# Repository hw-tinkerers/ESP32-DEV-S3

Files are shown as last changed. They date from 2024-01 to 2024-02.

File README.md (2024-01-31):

# ESP32-S3_Dev_Board
This development board is based on ESP32-S3 chipset which is aimed to solve the problem having to carry multiple tools to debug and capture data on RS485 and CAN bus.

<strong> Front view (Rendering)</strong>
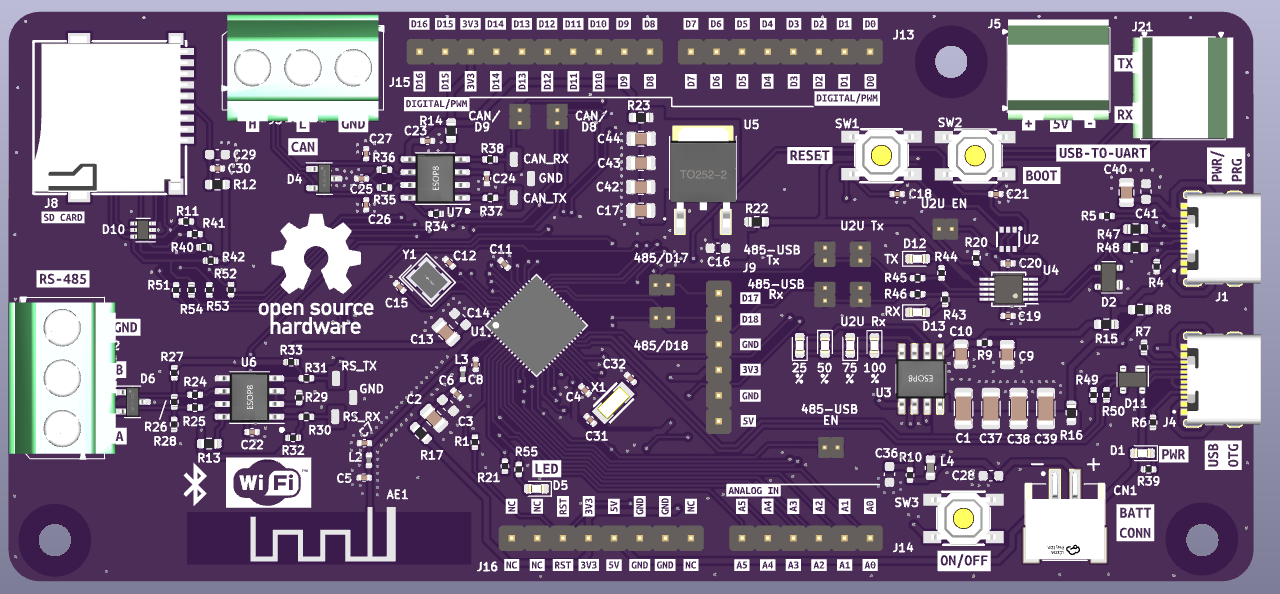
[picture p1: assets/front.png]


<strong> Back view (Rendering)</strong>
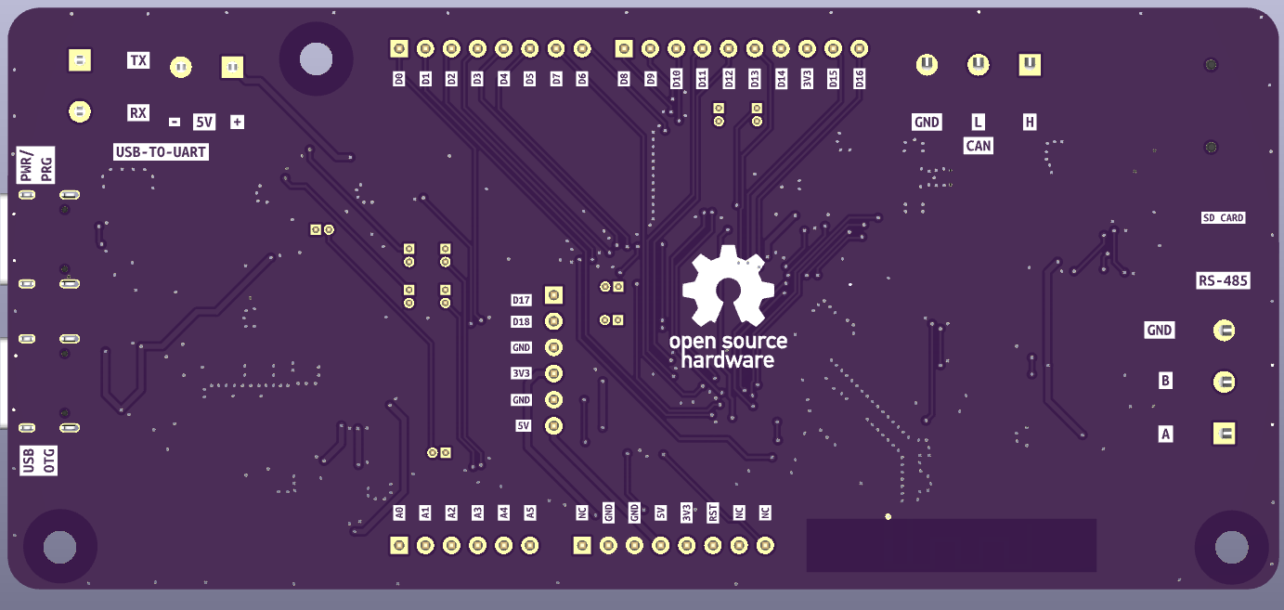
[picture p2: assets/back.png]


The board is capable of operating in multiple modes.
1. With Firmware support (Still in making):
    1. CAN bus Decoder
    2. RS485 Decoder 

2. Standalone Hardware support:
    1. RS485 to USB converter
    2. USB to UART converter

3. Normal Development baord for ESP32-S3 Development.

<strong>The Board supports a wide variety of features.</strong>

| Interface | Controller | Driver/Component |
| --- | --- | --- |
| UART | on-chip | serial port |
GPIO | on-chip | gpio |
PINMUX | on-chip | pinmux |
USB-JTAG | on-chip | hardware interface
SPI Master | on-chip | spi
TWAI/CAN controller | on-chip | can
ADC | on-chip | adc
Timers | on-chip | counter
Watchdog | on-chip | watchdog	
TRNG | on-chip | entropy
MCPWM | on-chip | pwm 
PCNT | on-chip | qdec
GDMA | on-chip | dma
LEDC | on-chip | pwm
CAN trasnceiver | on-board | can
RS485 transceiver | on-board | serial-port
UART-to-USB | on-board | Hardare based

<strong>Development enviroinment support </strong>
The board is designed keeping open-source support in mind.
The main motive is to provide support on multiple development environments to cater to different people ranging from begginers to professionls. 

The supported platforms are listed below

1. Arduino IDE
2. ESP-IDF
3. Zephyr-RTOS

The guide on getting started on each platform is still in making. Stay tuned for further updates.

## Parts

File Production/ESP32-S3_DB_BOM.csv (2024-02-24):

Designator | Footprint | Qty | Value | LCSC Part Number | MFR PN
C1, C37, C38, C39 | ESP32-S3_Dev_Board:C_1206_3216Metric | 4 | 22uF | C12891 | CL31A226KAHNNNE
C2, C9, C10, C13, C17, C40, C42, C43, C44 | ESP32-S3_Dev_Board:C_0805_2012Metric | 9 | 10uF | C15850 | CL21A106KAYNNNE
C3, C14, C16, C29, C41 | ESP32-S3_Dev_Board:C_0603_1608Metric | 5 | 1uF | C14664 | CC0603KRX5R8BB105
C4, C6, C8, C11, C18, C19, C20, C21, C22, C23, C24, C30 | ESP32-S3_Dev_Board:C_0402_1005Metric | 12 | 100nF | C2173920 | EMK107B7104KAHT
C5, C7 | ESP32-S3_Dev_Board:C_0402_1005Metric | 2 | 3.3pF | C327287 | CC0402BRNPO9BN3R3
C12, C15, C31, C32 | ESP32-S3_Dev_Board:C_0402_1005Metric | 4 | 15pF | C326789 | CC0402GRNPO8BN150
C25 | ESP32-S3_Dev_Board:C_0402_1005Metric | 1 | 10nF | C458948 | MT15B103K250CT
C28, C36 | ESP32-S3_Dev_Board:C_0603_1608Metric | 2 | 22uF | C2762594 | CL10A226MO7JZNC
CN1 | ESP32-S3_Dev_Board:JST_2mm | 1 | JST_Battery | C295747 | S2B-PH-SM4-TB(LF)(SN)
D1 | ESP32-S3_Dev_Board:LED_0603_1608Metric | 1 | BLUE | C84266 | NCD0603B1
D2, D11 | ESP32-S3_Dev_Board:SOT-143 | 2 | PRTR5V0U2X | C2827688 | PRTR5V0U2X
D3, D5, D7, D8, D9, D12, D13 | ESP32-S3_Dev_Board:LED_0603_1608Metric | 7 | GREEN | C84264 | NCD0603C1
D4 | ESP32-S3_Dev_Board:SOT-23-3 | 1 | PESD2CAN | C284078 | PESD2CAN
D6 | ESP32-S3_Dev_Board:SOT-23-3 | 1 | SM712_C293966 | C293966 | SM712
D10 | ESP32-S3_Dev_Board:SOT-363_SC-70-6 | 1 | PESD3V3L5UY,115 | C477992 | PESD3V3L5UY,115
J1, J4 | ESP32-S3_Dev_Board:tyye_c_connector | 2 | TYPE-C-31-M12_13 | C165948 | TYPE-C-31-M-12
J8 | ESP32-S3_Dev_Board:TF-SMD_TF-012 | 1 | Micro_SD_Card_Det1 | C5333937 | TF-012-P9
L2, L3 | ESP32-S3_Dev_Board:L_0402_1005Metric | 2 | 2.2nH | C76790 | MLK1005S2N2ST000
L4 | ESP32-S3_Dev_Board:L_0603_1608Metric | 1 | 1uH | C576540 | LQM18PN1R0MFHD
R1, R11, R21, R27, R28, R29, R40, R41, R42 | ESP32-S3_Dev_Board:R_0402_1005Metric | 9 | 10k | C60490 | RC0402FR-0710KL
R36, R35 | ESP32-S3_Dev_Board:R_0402_1005Metric | 2 | 59E | C273340 | RC0402FR-0759RL
R4, R5, R6, R7, R20, R32, R33, R34 | ESP32-S3_Dev_Board:R_0402_1005Metric | 8 | 5k1 | C105872 | RC0402FR-075K1L
R9 | ESP32-S3_Dev_Board:R_0402_1005Metric | 1 | 2E | C477639 | RC0402FR-072R1L
R10 | ESP32-S3_Dev_Board:R_0402_1005Metric | 1 | 0.5E | C346785 | CSR0402FKR500
R12, R13, R14, R15, R16, R17, R22, R23, R47, R48 | ESP32-S3_Dev_Board:R_0603_1608Metric | 10 | 0E | C95177 | RC0603JR-070RL
R24, R25, R30, R31, R37, R38, R45, R46, R49, R50, R51, R52, R53, R54 | ESP32-S3_Dev_Board:R_0402_1005Metric | 14 | 10E | C102753 | RTT02100JTH
R26 | ESP32-S3_Dev_Board:R_0402_1005Metric | 1 | 120E | C114758 | RC0402FR-07120RL
R39, R43, R44, R55 | ESP32-S3_Dev_Board:R_0402_1005Metric | 4 | 500 | C137970 | RC0402FR-07499RL
SW1 | ESP32-S3_Dev_Board:KEY-SMD_4P-L5.2-W5.2-P3.70-LS6.4 | 1 | RESET | C92584 | K2-1187SQ-A4SW-06
SW2 | ESP32-S3_Dev_Board:KEY-SMD_4P-L5.2-W5.2-P3.70-LS6.4 | 1 | BOOT | C92584 | K2-1187SQ-A4SW-06
SW3 | ESP32-S3_Dev_Board:KEY-SMD_4P-L5.2-W5.2-P3.70-LS6.4 | 1 | ON/OFF | C92584 | K2-1187SQ-A4SW-06
U1 | ESP32-S3_Dev_Board:QFN-56_L7.0-W7.0-P0.40-TL-EP4.0 | 1 | ESP32-S3FH4R2 | C3013940 | ESP32-S3FH4R2
U2 | ESP32-S3_Dev_Board:SC-70-6_L2.2-W1.3-P0.65-LS2.1-BR | 1 | UMH3N | C62892 | UMH3N
U3 | ESP32-S3_Dev_Board:ESOP-8 | 1 | IP5306 | C181692 | IP5306
U4 | ESP32-S3_Dev_Board:MSOP-10_3x3mm_P0.5mm | 1 | CH340X | C3035748 | CH340X
U5 | ESP32-S3_Dev_Board:DPAK | 1 | LD1117DT33CTR | C36395 | LD1117DT33CTR
U6 | ESP32-S3_Dev_Board:SOP-8_3.9x4.9mm_P1.27mm | 1 | SP3071EEN-L/TR | C28746 | SP3071EEN-L/TR
U7 | ESP32-S3_Dev_Board:SOP-8_3.9x4.9mm_P1.27mm | 1 | ATA6561-GAQW-N | C616016 | ATA6561-GAQW-N
X1 | ESP32-S3_Dev_Board:CRYSTAL-SMD_L3.2-W1.5 | 1 | 32.768KHz | C7206317 | RN32768016
Y1 | ESP32-S3_Dev_Board:CRYSTAL-SMD_4P-L3.2-W2.5-BL | 1 | 40MHz | C2901712 | SX3B40.000F1210F30

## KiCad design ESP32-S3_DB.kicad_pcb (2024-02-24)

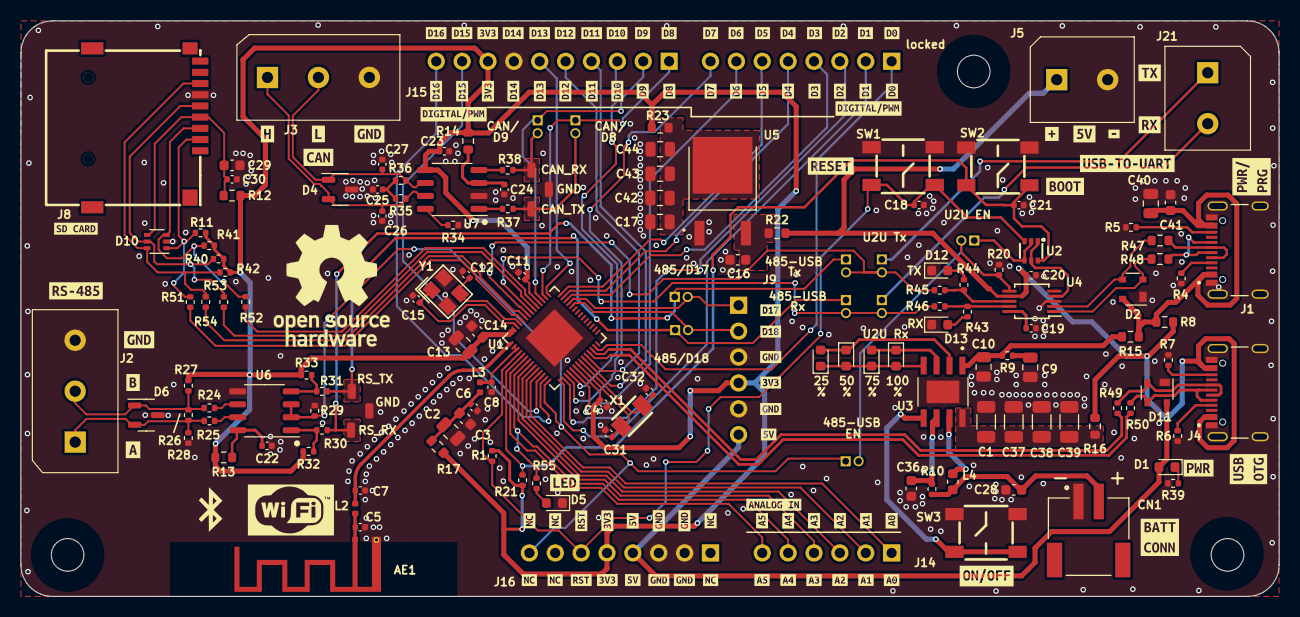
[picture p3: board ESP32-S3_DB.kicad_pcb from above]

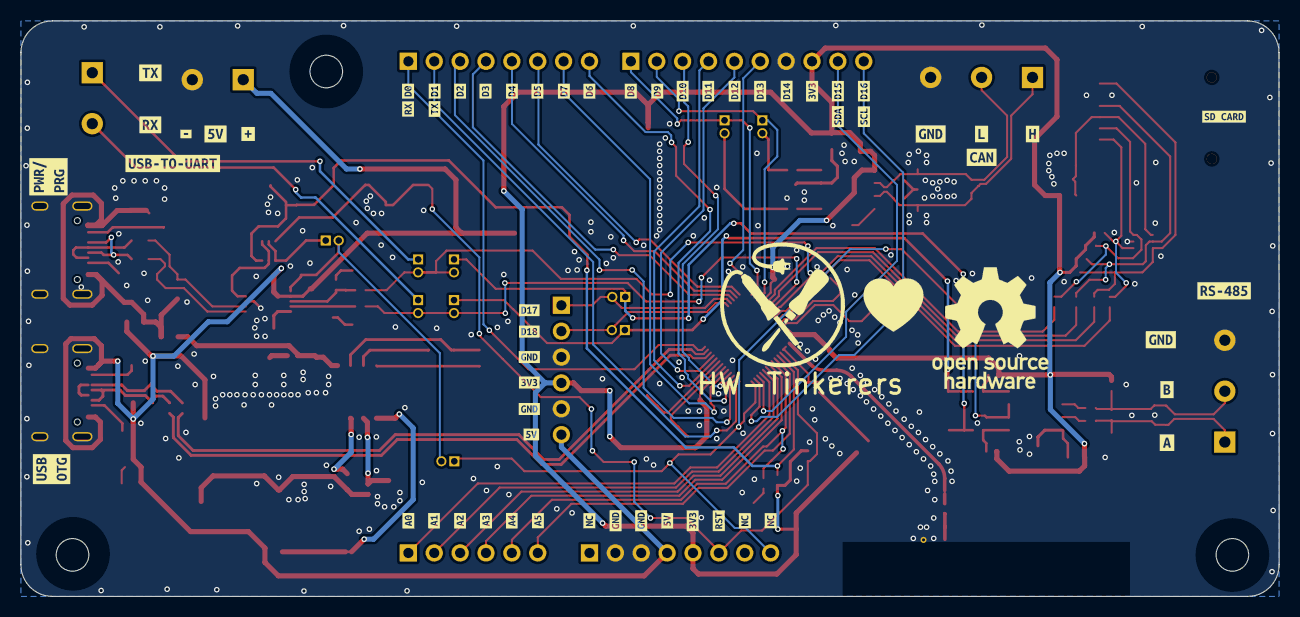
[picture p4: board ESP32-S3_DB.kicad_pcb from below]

Board: 4 copper layers, 123.5 x 56.5 mm, 310 parts (60 on the bottom side), 104 nets.

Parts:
AE1: Antenna_Shield; BLE_ANTENNA
C1, C37, C38, C39: 22uF; C_1206_3216Metric
C2, C9, C10, C13, C17, C40, C42, C43, C44: 10uF; C_0805_2012Metric
C3, C14, C16, C29, C41: 1uF; C_0603_1608Metric
C4, C6, C8, C11, C18, C19, C20, C21, C22, C23, C24, C30: 100nF; C_0402_1005Metric
C5, C7: 3.3pF; C_0402_1005Metric
C12, C15, C31, C32: 15pF; C_0402_1005Metric
C25, C26, C27: 10nF; C_0402_1005Metric
C28, C36: 22uF; C_0603_1608Metric
CN1: JST_Battery; JST_2mm
D1: BLUE; LED_0603_1608Metric
D2, D11: PRTR5V0U2X; SOT-143
D3, D5, D7, D8, D9, D12, D13: GREEN; LED_0603_1608Metric
D4: PESD2CAN; SOT-23-3
D6: SM712_C293966; SOT-23-3
D10: PESD3V3L5UY,115; SOT-363_SC-70-6
H1, H2, H3: MountingHole; MountingHole_3.2mm_M3
J1, J4: TYPE-C-31-M12_13; tyye_c_connector
J2: A - B; 3P_Screw_Terminal
J3: H - L; 3P_Screw_Terminal
J5: EXT_LOAD; 2P_Screw_Terminal
J6: R4_TX; PinHeader_1x02_P1.27mm_Vertical
J7: R4_RX; PinHeader_1x02_P1.27mm_Vertical
J8: Micro_SD_Card_Det1; TF-SMD_TF-012
J9, J14: Conn_01x06; PinHeader_1x06_P2.54mm_Vertical
J10: U2RS485_TX; PinHeader_1x02_P1.27mm_Vertical
J11: CAN_TX; PinHeader_1x02_P1.27mm_Vertical
J12: CAN_RX; PinHeader_1x02_P1.27mm_Vertical
J15: Conn_01x10; PinHeader_1x10_P2.54mm_Vertical
J16: Conn_01x08; PinHeader_1x08_P2.54mm_Vertical
J17: U2RS485_RX; PinHeader_1x02_P1.27mm_Vertical
J18: U2RS485_DE_~{RE}; PinHeader_1x02_P1.27mm_Vertical
J19: U2U_TX; PinHeader_1x02_P1.27mm_Vertical
J20: U2U_RX; PinHeader_1x02_P1.27mm_Vertical
J21: U2U; 2P_Screw_Terminal
J22: PROG_Default; PinHeader_1x02_P1.27mm_Vertical
L2, L3: 2.2nH; L_0402_1005Metric
L4: 1uH; L_0603_1608Metric
R1, R11, R21, R27, R28, R29, R40, R41, R42: 10k; R_0402_1005Metric
R4, R5, R6, R7, R20, R32, R33, R34: 5k1; R_0402_1005Metric
R8, R12, R13, R14, R15, R16, R17, R22, R23, R47, R48: 0E; R_0603_1608Metric
R9: 2E; R_0402_1005Metric
R10: 0.5E; R_0402_1005Metric
R24, R25, R30, R31, R37, R38, R45, R46, R49, R50, R51, R52, R53, R54: 10E; R_0402_1005Metric
R26: 120E; R_0402_1005Metric
R35: 59E; R_0402_1005Metric
R36: 59; R_0402_1005Metric
R39, R43, R44, R55: 500; R_0402_1005Metric
SW1: RESET; KEY-SMD_4P-L5.2-W5.2-P3.70-LS6.4
SW2: BOOT; KEY-SMD_4P-L5.2-W5.2-P3.70-LS6.4
SW3: ON/OFF; KEY-SMD_4P-L5.2-W5.2-P3.70-LS6.4
SYM1, SYM2: Logo_Open_Hardware_Large; OSHW-Logo_11.4x12mm_SilkScreen
TP1: RS_RX; Test_Pad_1.5mm
TP2: RS_TX; Test_Pad_1.5mm
TP3: CAN_TX; Test_Pad_1.5mm
TP4: CAN_RX; Test_Pad_1.5mm
TP5, TP6: GND; Test_Pad_1.5mm
U1: ESP32-S3FH4R2; QFN-56_L7.0-W7.0-P0.40-TL-EP4.0
U2: UMH3N; SC-70-6_L2.2-W1.3-P0.65-LS2.1-BR
U3: IP5306; ESOP-8
U4: CH340X; MSOP-10_3x3mm_P0.5mm
U5: LD1117DT33CTR; DPAK
U6: SP3071EEN-L/TR; SOP-8_3.9x4.9mm_P1.27mm
U7: ATA6561-GAQW-N; SOP-8_3.9x4.9mm_P1.27mm
X1: 32.768KHz; CRYSTAL-SMD_L3.2-W1.5
Y1: 40MHz; CRYSTAL-SMD_4P-L3.2-W2.5-BL
kibuzzard-65A92C15, kibuzzard-65A92C15#2, kibuzzard-65A92C15#3: G***; kibuzzard-65A92C15
kibuzzard-65A92C32, kibuzzard-65A92C32#2, kibuzzard-65A92C32#3: G***; kibuzzard-65A92C32
kibuzzard-65A92C44, kibuzzard-65A92C44#2, kibuzzard-65A92C44#3: G***; kibuzzard-65A92C44
kibuzzard-65A92C55, kibuzzard-65A92C55#2, kibuzzard-65A92C55#3: G***; kibuzzard-65A92C55
kibuzzard-65A92C85, kibuzzard-65A92C85#2, kibuzzard-65A92C85#3: G***; kibuzzard-65A92C85
kibuzzard-65A92C90, kibuzzard-65A92C90#2, kibuzzard-65A92C90#3: G***; kibuzzard-65A92C90
kibuzzard-65A92C99, kibuzzard-65A92C99#2, kibuzzard-65A92C99#3: G***; kibuzzard-65A92C99
kibuzzard-65A92CA3, kibuzzard-65A92CA3#2, kibuzzard-65A92CA3#3: G***; kibuzzard-65A92CA3
kibuzzard-65A92CE7, kibuzzard-65A92CE7#2: G***; kibuzzard-65A92CE7
kibuzzard-65A92E71, kibuzzard-65A92E71#2: G***; kibuzzard-65A92E71
kibuzzard-65A922D3, kibuzzard-65A922D3#2, kibuzzard-65A922D3#3: G***; kibuzzard-65A922D3
kibuzzard-65A922DA, kibuzzard-65A922DA#2, kibuzzard-65A922DA#3: G***; kibuzzard-65A922DA
kibuzzard-65A922E0, kibuzzard-65A922E0#2, kibuzzard-65A922E0#3: G***; kibuzzard-65A922E0
kibuzzard-65A922F7, kibuzzard-65A922F7#2, kibuzzard-65A922F7#3: G***; kibuzzard-65A922F7
kibuzzard-65A932A3, kibuzzard-65A932A3#2: G***; kibuzzard-65A932A3
kibuzzard-65A932F7, kibuzzard-65A932F7#2: G***; kibuzzard-65A932F7
kibuzzard-65A934AB, kibuzzard-65A934AB#2: G***; kibuzzard-65A934AB
kibuzzard-65A937AF, kibuzzard-65A937AF#2: G***; kibuzzard-65A937AF
kibuzzard-65A937DF: G***; kibuzzard-65A937DF
kibuzzard-65A9230D, kibuzzard-65A9230D#2, kibuzzard-65A9230D#3: G***; kibuzzard-65A9230D
kibuzzard-65A9357B: G***; kibuzzard-65A9357B
kibuzzard-65A9398B, kibuzzard-65A9398B#2: G***; kibuzzard-65A9398B
kibuzzard-65A92320, kibuzzard-65A92320#2, kibuzzard-65A92320#3: G***; kibuzzard-65A92320
kibuzzard-65A92621: G***; kibuzzard-65A92621
kibuzzard-65A93244, kibuzzard-65A93244#2: G***; kibuzzard-65A93244
kibuzzard-65A93266, kibuzzard-65A93266#2: G***; kibuzzard-65A93266
kibuzzard-65A93272, kibuzzard-65A93272#2: G***; kibuzzard-65A93272
kibuzzard-65A93313, kibuzzard-65A93313#2: G***; kibuzzard-65A93313
kibuzzard-65A93322, kibuzzard-65A93322#2: G***; kibuzzard-65A93322
kibuzzard-65A93334, kibuzzard-65A93334#2: G***; kibuzzard-65A93334
kibuzzard-65A93499, kibuzzard-65A93499#2: G***; kibuzzard-65A93499
kibuzzard-65A93960, kibuzzard-65A93960#2: G***; kibuzzard-65A93960
kibuzzard-65AB7A1C: G***; kibuzzard-65AB7A1C
kibuzzard-65AB7A3B, kibuzzard-65AB7A3B#2: G***; kibuzzard-65AB7A3B
kibuzzard-65AB7A4E, kibuzzard-65AB7A4E#2: G***; kibuzzard-65AB7A4E
kibuzzard-65AB7A5E, kibuzzard-65AB7A5E#2: G***; kibuzzard-65AB7A5E
kibuzzard-65AB7A9A, kibuzzard-65AB7A9A#2: G***; kibuzzard-65AB7A9A
kibuzzard-65AB7A9F: G***; kibuzzard-65AB7A9F
kibuzzard-65AB7A26, kibuzzard-65AB7A26#2: G***; kibuzzard-65AB7A26
kibuzzard-65AB7A41: G***; kibuzzard-65AB7A41
kibuzzard-65AB7A48: G***; kibuzzard-65AB7A48
kibuzzard-65AB7A58: G***; kibuzzard-65AB7A58
kibuzzard-65AB7A95: G***; kibuzzard-65AB7A95
kibuzzard-65AB7AA6, kibuzzard-65AB7AA6#2: G***; kibuzzard-65AB7AA6
kibuzzard-65AB7AAC: G***; kibuzzard-65AB7AAC
kibuzzard-65AB7AB4, kibuzzard-65AB7AB4#2: G***; kibuzzard-65AB7AB4
kibuzzard-65AB7ABA: G***; kibuzzard-65AB7ABA
kibuzzard-65AB7AC0, kibuzzard-65AB7AC0#2: G***; kibuzzard-65AB7AC0
kibuzzard-65AB7B50: G***; kibuzzard-65AB7B50
kibuzzard-65AB7B59, kibuzzard-65AB7B59#2: G***; kibuzzard-65AB7B59
kibuzzard-65AB7B60: G***; kibuzzard-65AB7B60
kibuzzard-65AB7B68, kibuzzard-65AB7B68#2: G***; kibuzzard-65AB7B68
kibuzzard-65AB72BB, kibuzzard-65AB72BB#2, kibuzzard-65AB72BB#3: G***; kibuzzard-65AB72BB
kibuzzard-65AB72CF, kibuzzard-65AB72CF#2, kibuzzard-65AB72CF#3: G***; kibuzzard-65AB72CF
kibuzzard-65AB99D3, kibuzzard-65AB99D3#2: G***; kibuzzard-65AB99D3
kibuzzard-65AB729F, kibuzzard-65AB729F#2, kibuzzard-65AB729F#3, kibuzzard-65AB729F#4, kibuzzard-65AB729F#5, kibuzzard-65AB729F#6: G***; kibuzzard-65AB729F
kibuzzard-65AB730A, kibuzzard-65AB730A#2, kibuzzard-65AB730A#3: G***; kibuzzard-65AB730A
kibuzzard-65AB731E, kibuzzard-65AB731E#2, kibuzzard-65AB731E#3, kibuzzard-65AB731E#4, kibuzzard-65AB731E#5, kibuzzard-65AB731E#6: G***; kibuzzard-65AB731E
kibuzzard-65AB7281, kibuzzard-65AB7281#2, kibuzzard-65AB7281#3: G***; kibuzzard-65AB7281
kibuzzard-65ABCD1E, kibuzzard-65ABCD1E#2: G***; kibuzzard-65ABCD1E
kibuzzard-65ABCD6A, kibuzzard-65ABCD6A#2: G***; kibuzzard-65ABCD6A
kibuzzard-65ABCD30, kibuzzard-65ABCD30#2: G***; kibuzzard-65ABCD30
kibuzzard-65ABCD42, kibuzzard-65ABCD42#2, kibuzzard-65ABCD42#3, kibuzzard-65ABCD42#4: G***; kibuzzard-65ABCD42
kibuzzard-65ABCD53, kibuzzard-65ABCD53#2: G***; kibuzzard-65ABCD53
kibuzzard-65ABCFED: G***; kibuzzard-65ABCFED
kibuzzard-65ABD001: G***; kibuzzard-65ABD001
kibuzzard-65ABD06D, kibuzzard-65ABD06D#2: G***; kibuzzard-65ABD06D
kibuzzard-65ABD087, kibuzzard-65ABD087#2: G***; kibuzzard-65ABD087
kibuzzard-65AD136A: G***; kibuzzard-65AD136A
kibuzzard-65AD1381: G***; kibuzzard-65AD1381
kibuzzard-65CC7CB6: G***; kibuzzard-65CC7CB6
kibuzzard-65CC7CF4: G***; kibuzzard-65CC7CF4
kibuzzard-65CDB80D: G***; kibuzzard-65CDB80D
kibuzzard-65CDB868: G***; kibuzzard-65CDB868
locked: Conn_01x08; PinHeader_1x08_P2.54mm_Vertical

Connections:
/3V3: C4.1, C11.1, C13.1, C14.1, C23.1, J9.4, J15.8, J16.5, R1.1, R11.2, R12.1, R13.2, R14.1, R17.1, R21.1, R23.2, R27.2, R32.2, R33.2, R40.2, R41.2, R42.2, U1.20 (VDD3P3_RTC), U1.46 (VDD3P3_CPU), U1.55 (VDDA), U1.56 (VDDA), U7.5 (VIO)
/5V: C20.2, D1.2 (A), D11.4 (VCC), J4.A4 (VBUS), J4.B4 (VBUS), J5.1, J9.6, J16.4, R8.2, R16.2, R22.1, U4.7 (VCC)
/485_TRANS_RX: J7.1, J17.1, R30.1, TP1.1
/485_TRANS_TX: J6.1, J10.1, R31.1, TP2.1
/BOOT: C21.2, R21.2, SW2.2, U1.5 (GPIO0), U2.6
/CAN TRANSCEIVER/RXD: R38.1, U7.4 (RXD)
/CAN TRANSCEIVER/TXD: R37.1, U7.1 (TXD)
/CAN_N: C27.2, D4.1, J3.2, R36.1, U7.6 (CANL)
/CAN_P: C26.1, D4.2, J3.1, R35.2, U7.7 (CANH)
/CAN_RXD/MTDO: J12.1, J15.2, U1.45 (MTDO)
/CAN_TRANS_RXD: J12.2, R38.2, TP4.1
/CAN_TRANS_TXD: J11.2, R37.2, TP3.1
/CAN_TXD/MTCK: J11.1, J15.1, U1.44 (MTCK)
/D+: D2.2 (I/O_1), R48.2, U4.1 (UD+)
/D-: D2.3 (I/O_2), R47.2, U4.2 (UD-)
/ESP32-S3/D+: R49.2, U1.26 (GPIO20)
/ESP32-S3/D-: R50.2, U1.25 (GPIO19)
/ESP32-S3/XTALN: C32.1, U1.22 (XTAL_32K_N), X1.2
/ESP32-S3/XTALP: C31.1, U1.21 (XTAL_32K_P), X1.1
/EXTERNAL CONNECTORS/CC1: J4.A5 (CC1), R6.1
/EXTERNAL CONNECTORS/CC2: J4.B5 (CC2), R7.1
/GPIO1: J14.6, U1.6 (GPIO1)
/GPIO2: J14.5, R55.2, U1.7 (GPIO2)
/GPIO3: J14.4, U1.8 (GPIO3)
/GPIO4: J14.3, U1.9 (GPIO4)
/GPIO5: J14.2, U1.10 (GPIO5)
/GPIO6: J14.1, U1.11 (GPIO6)
/GPIO7: J15.9, U1.12 (GPIO7)
/GPIO8: J15.10, U1.13 (GPIO8)
/GPIO10: U1.15 (GPIO10), locked.2
/GPIO11: U1.16 (GPIO11), locked.3
/GPIO12: U1.17 (GPIO12), locked.8
/GPIO13: J15.3, U1.18 (GPIO13)
/GPIO14: U1.19 (GPIO14), locked.7
/GPIO17: J15.4, U1.23 (GPIO17)
/GPIO18: J15.5, U1.24 (GPIO18)
/GPIO21: U1.27 (GPIO21), locked.1
/GPIO35: U1.40 (GPIO35), locked.4
/GPIO36: U1.41 (GPIO36), locked.5
/GPIO37: U1.42 (GPIO37), locked.6
/GPIO40: J15.6, U1.43 (GPIO38)
/INPUT POWER/CC1: J1.A5 (CC1), R4.1
/INPUT POWER/CC2: J1.B5 (CC2), R5.1
/INPUT POWER/LED1: D3.2 (A), D7.1 (K), U3.2 (LED1)
/INPUT POWER/LED2: D8.2 (A), D9.1 (K), U3.3 (LED2)
/INPUT POWER/LED3: D3.1 (K), D7.2 (A), D8.1 (K), D9.2 (A), U3.4 (LED3)
/INPUT POWER/VIN: C40.1, C41.1, D2.4 (VCC), J1.A4 (VBUS), J1.B4 (VBUS), R8.1, R15.1
/MCU_SL_CLK: D10.5 (L4), J8.5 (CLK), R40.1, R53.1
/MCU_SL_MISO: D10.6 (L5), J8.7 (DAT0), R42.1, R54.2
/MCU_SL_MOSI: D10.3 (L2), J8.3 (CMD), R41.1, R52.2
/OTG_D+: D11.2 (I/O_1), J4.A6 (D+), J4.B6 (D+), R49.1
/OTG_D-: D11.3 (I/O_2), J4.A7 (D-), J4.B7 (D-), R50.1
/R4_~RE_DE: J16.8, J18.1, R29.2, U1.14 (GPIO9), U6.2 (~RE), U6.3 (DE)
/RESET: C18.2, J16.6, R1.2, SW1.2, U1.4 (CHIP_PU), U2.3
/RS485_N: D6.2, J2.1, R25.2, R26.1, R28.2
/RS485_P: D6.1, J2.2, R24.2, R26.2, R27.1
/RS-485_RX/GPIO34: J7.2, J9.1, U1.39 (GPIO34)
/RS-485_TX/GPIO33: J6.2, J9.2, U1.38 (GPIO33)
/RS_485/RS-485_DI: R31.2, R33.1, U6.4 (DI)
/RS_485/RS-485_RO: R30.2, R32.1, U6.1 (RO)
/RS_485/RS_485_N: R25.1, U6.7 (B)
/RS_485/RS_485_P: R24.1, U6.6 (A)
/SD_CARD/VDD: C29.1, C30.1, D10.4 (L3), J8.4 (VDD), R12.2
/TNOW: J18.2, J22.2, R20.2, U4.6 (TNOW)
/U2U_CONN_RX: J20.1, J21.2
/U2U_CONN_TX: J19.1, J21.1
/U2U_RXD: J10.2, J20.2, R46.2, U1.49 (U0TXD)
/U2U_TXD: J17.2, J19.2, R45.2, U1.50 (U0RXD)
/USB-TO-UART/485_TX: R44.2, R45.1, U4.8 (TXD)
/USB-TO-UART/DTR: J22.1, U2.2, U2.4
/USB-TO-UART/RTS: U2.1, U2.5, U4.4 (~RTS)
/USB-TO-UART/V3: C19.2, U4.10 (V3)
/V_BAT: C28.1, CN1.2, L4.2, R10.2
/~MCU_SL_CS: D10.1 (L1), J8.2 (DAT3/CD), R11.1, R51.1
GND: AE1.2 (Shield), C1.2, C2.2, C3.2, C4.2, C5.2, C6.2, C7.2, C8.2, C9.2, C10.2, C11.2, C12.2, C13.2, C14.2, C15.2, C16.2, C17.2, C18.1, C19.1, C20.1, C21.1, C22.2, C23.2, C24.1, C25.1, C26.2, C27.1, C28.2, C29.2, C30.2, C31.2, C32.2, C36.2, C37.2, C38.2, C39.2, C40.2, C41.2, C42.2, C43.2, C44.2, CN1.1, D2.1 (GND), D4.3, D5.1 (K), D6.3, D10.2 (VN), D11.1 (GND), D12.1 (K), D13.1 (K), J1.A1 (GND), J1.B1 (GND), J1.S (SHIELD), J2.3, J3.3, J4.A1 (GND), J4.B1 (GND), J4.S (SHIELD), J5.2, J8.6 (VSS), J9.3, J9.5, J15.7, J16.2, J16.3, R4.2, R5.2, R6.2, R7.2, R20.1, R28.1, R29.1, R34.2, R39.2, SW1.1, SW2.1, SW3.2, TP5.1, TP6.1, U1.57 (GND), U3.9 (EP), U4.3 (GND), U5.1 (GND), U6.5 (GND), U7.2 (GND), Y1.2, Y1.4
unnamed: AE1.1 (A), C5.1, L2.1
unnamed: C2.1, C3.1, C6.1, L3.1, R17.2
unnamed: C8.1, L3.2, U1.2 (VDD3P3), U1.3 (VDD3P3)
unnamed: C9.1, R9.2
unnamed: C25.2, R35.1, R36.2
unnamed: D1.1 (K), R39.1
unnamed: D5.2 (A), R55.1
unnamed: D12.2 (A), R44.1
unnamed: D13.2 (A), R43.1
unnamed: J1.A6 (D+), J1.B6 (D+), R48.1
unnamed: J1.A7 (D-), J1.B7 (D-), R47.1
unnamed: R54.1, U1.51 (GPIO45)
unnamed: R51.2, U1.52 (GPIO46)
unnamed: C7.1, L2.2, U1.1 (LNA_IN)
unnamed: R52.1, U1.47 (MTDI)
unnamed: R53.2, U1.48 (MTMS)
unnamed: C12.1, U1.53 (XTAL_N), Y1.3
unnamed: C15.1, U1.54 (XTAL_P), Y1.1
unnamed: C36.1, R10.1, U3.6 (BAT)
unnamed: SW3.1, U3.5 (KEY)
unnamed: L4.1, U3.7 (SW)
unnamed: C10.1, R9.1, R15.2, U3.1 (VIN)
unnamed: C1.1, C37.1, C38.1, C39.1, R16.1, U3.8 (VOUT)
unnamed: R43.2, R46.1, U4.9 (RXD)
unnamed: C16.1, R22.2, U5.3 (VIN)
unnamed: C17.1, C42.1, C43.1, C44.1, R23.1, U5.2 (VOUT)
unnamed: C22.1, R13.1, U6.8 (VCC)
unnamed: R34.1, U7.8 (STBY)
unnamed: C24.2, R14.2, U7.3 (VCC)

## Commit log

2023-08-22 Schematic file with Symbol library
    [ESP32-S3_DB.kicad_pcb, ESP32-S3_DB.kicad_sch]
2023-08-22 Started designed the schematics
    Placed passives for supply pins and antenna
    [ESP32-S3_DB.kicad_sch]
2023-08-23 Added External Flash and Power sheets
    Added External Flash and Power sheets. Finished adding all the passives at their respective pins. Incorrect Pin number and signal corrected.
    [ESP32-S3_DB.kicad_sch, EXT_FLASH.kicad_sch, POWER.kicad_sch]
2023-09-04 Created Block arrangement and added USB C connector
    [3V3_Power.kicad_sch, ESP32-S3-MCU.kicad_sch, ESP32-S3_DB.kicad_sch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]
2023-09-04 completed USB-C wiring and added flash
    [ESP32-S3_DB.kicad_sch, EXT_FLASH.kicad_sch, INPUT POWER.kicad_sch]
2023-09-06 Added USB-To-UART Converter
    [ESP32-S3-MCU.kicad_sch, ESP32-S3_DB.kicad_sch, EXT_FLASH.kicad_sch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]
2023-09-12 Made USB-To-UART connections
    [ESP32-S3-MCU.kicad_sch, ESP32-S3_DB.kicad_sch, USB-To-UART.kicad_sch]
2023-09-16 Added RS-485 Transceiver
    [3V3_Power.kicad_sch, ESP32-S3-MCU.kicad_sch, ESP32-S3_DB.kicad_sch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]
2023-09-17 Minor UART corrections
2023-09-17 UART Tx and Rx correctly placed
    [ESP32-S3_DB.kicad_sch, USB-To-UART.kicad_sch]
2023-09-17 Completed RS-485 connections
    [CAN-TRANSCEIVER.kicad_sch, ESP32-S3-MCU.kicad_sch, ESP32-S3_DB.kicad_sch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]
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2023-09-18 Added IP5306 for power path management
    [CAN-TRANSCEIVER.kicad_sch, ESP32-S3-MCU.kicad_sch, ESP32-S3_DB.kicad_sch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]
2023-09-19 Assigned UART port 2 for RS-485
    [ESP32-S3-MCU.kicad_sch, ESP32-S3_DB.kicad_sch, External_connec.kicad_sch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]
2023-09-21 Added SD card interface
    [ESP32-S3-MCU.kicad_sch, ESP32-S3_DB.kicad_sch, SD_Card.kicad_sch]
2023-09-23 Added SD card protection
    [ESP32-S3_DB.kicad_sch, SD_Card.kicad_sch]
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2023-09-24 Added 32.768KHz crystal for lower power usage
    [ESP32-S3-MCU.kicad_sch]
2023-09-27 Assigned PN and Footprint for C
    [3V3_Power.kicad_sch, CAN-TRANSCEIVER.kicad_sch, ESP32-S3-MCU.kicad_sch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]
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2023-10-16 Arranged power section on PCB
    [ESP32-S3_DB.kicad_pcb, ESP32-S3_DB.kicad_sch, INPUT POWER.kicad_sch]
2023-10-18 Added bulk Decoupling and arranged components
    [3V3_Power.kicad_sch, ESP32-S3-MCU.kicad_sch, ESP32-S3_DB.kicad_pcb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]
2023-10-20 Changed USB C footprint and arranged components
    [ESP32-S3_DB.kicad_pcb, External_connec.kicad_sch, INPUT POWER.kicad_sch]
2023-10-22 Placed RS-485, CAN Transceiver and battery charger
    [CAN-TRANSCEIVER.kicad_sch, ESP32-S3-MCU.kicad_sch, ESP32-S3_DB.kicad_pcb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]
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2023-10-24 Placed all the components and added OSHW symbol
    [ESP32-S3-MCU.kicad_sch, ESP32-S3_DB.kicad_pcb, ESP32-S3_DB.kicad_sch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]
2023-10-25 Corrected schematic to PCB export error and warings and IP5306 and SD card section
    [3V3_Power.kicad_sch, ESP32-S3-MCU.kicad_sch, ESP32-S3_DB.kicad_pcb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]
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2023-10-27 Corrected RS485 schematic
    [3V3_Power.kicad_sch, CAN-TRANSCEIVER.kicad_sch, ESP32-S3_DB.kicad_sch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]
2023-10-27 Made minor changes in connectors sheet
    [ESP32-S3_DB.kicad_sch, External_connec.kicad_sch]
2023-10-27 Added CAN Jumpers, changed jumper pitch to 1.27mm
    [CAN-TRANSCEIVER.kicad_sch, ESP32-S3-MCU.kicad_sch, ESP32-S3_DB.kicad_pcb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]
2023-10-28 Changed GPIO headers to Arduino style
    [ESP32-S3_DB.kicad_pcb, ESP32-S3_DB.kicad_sch, External_connec.kicad_sch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]
2023-10-30 Arranged IP5306, Added support for USB-To-RS485
    [ESP32-S3_DB.kicad_pcb, ESP32-S3_DB.kicad_sch, External_connec.kicad_sch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]
2023-10-30 Arranged arduino headers as per the Uno R3 dimensions
    [ESP32-S3_DB.kicad_pcb]
2023-10-31 Minor changes in Arduino GPIO headers
    [ESP32-S3_DB.kicad_pcb]
2023-11-04 First draft of component layout
    [CAN-TRANSCEIVER.kicad_sch, ESP32-S3_DB.kicad_pcb, ESP32-S3_DB.kicad_sch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]
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2023-11-05 Added selection jumper sheet and USB-UART option for board
    [ESP32-S3_DB.kicad_sch, External_connec.kicad_sch, PCB_Attributes.kicad_sch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]
2023-11-27 Made aesthetic changes in Schematics
    [ESP32-S3_DB.kicad_sch, Selection_jumpers.kicad_sch]
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2023-11-29 Made changes in schematics, changed hierarchical sheet color
    [ESP32-S3-MCU.kicad_sch, ESP32-S3_DB.kicad_pcb, ESP32-S3_DB.kicad_sch]
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2023-12-23 Changed MCU pin mapping
    [ESP32-S3-MCU.kicad_sch, ESP32-S3_DB.kicad_pcb, ESP32-S3_DB.kicad_sch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]
2023-12-26 Completed routing for all GPIO pins
    [ESP32-S3-MCU.kicad_sch, ESP32-S3_DB.kicad_pcb, ESP32-S3_DB.kicad_sch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]
2023-12-26 Completed RS485 and CAN routing
    [ESP32-S3_DB.kicad_pcb, External_connectors.kicad_sch, RS_485.kicad_sch]
2023-12-27 Completed routing for USB peripheral for CH340
    [ESP32-S3_DB.kicad_pcb, External_connectors.kicad_sch, INPUT_POWER.kicad_sch]
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2024-01-17 Changed UART0 port connections
    [ESP32-S3-MCU.kicad_sch, ESP32-S3_DB.kicad_pcb]
2024-01-18 Changed GPIO39, 40 crossing and added GND vias near other vias
    [ESP32-S3-MCU.kicad_sch, ESP32-S3_DB.kicad_pcb]
2024-01-20 Added GND vias along antenna track, cleared tracks underneath antenna track
    [ESP32-S3_DB.kicad_pcb, External_connec.kicad_sch]
2024-01-20 Added Arduino style SS for GPIO headers, Added BLE & Wi-Fi symbol
    [ESP32-S3_DB.kicad_pcb, External_connec.kicad_sch, INPUT_POWER.kicad_sch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]
2024-01-21 Adjusted Wi-Fi and BLE logo, added SS for jumpers
    [ESP32-S3_DB.kicad_pcb]
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2024-01-31 Changed pin mapping for ESP
    [ESP32-S3-MCU.kicad_sch, ESP32-S3_DB.kicad_pcb]
2024-02-10 Solved DRC errors and improved routing
    [ESP32-S3_DB.kicad_pcb]
2024-02-13 Added selection jumper block diagram and solved DRC errors
    [ESP32-S3-MCU.kicad_sch, ESP32-S3_DB.kicad_pcb, ESP32-S3_DB.kicad_sch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]
2024-02-14 Added HW-Tinkerers logo and supporting graphics
    [3V3_Power.kicad_sch, CAN-TRANSCEIVER.kicad_sch, ESP32-S3-MCU.kicad_sch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]
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2024-02-24 Added production files for JLC (BOM and CPL)
    [3V3_Power.kicad_sch, CAN-TRANSCEIVER.kicad_sch, ESP32-S3-MCU.kicad_sch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]
